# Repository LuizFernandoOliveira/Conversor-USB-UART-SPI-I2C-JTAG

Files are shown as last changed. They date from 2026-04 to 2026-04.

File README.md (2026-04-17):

# Conversor-USB-UART-SPI-I2C-JTAG




## Descrição
Esta PCB trata-se de um poderoso circuito eletrônico que transforma uma única porta USB em múltiplos canais seriais de alta velocidade, ideal para desenvolvedores que precisam de versatilidade em seus projetos.

<p align="center">
  usb2UartSpiI2c
</p>

---

## Descrições técnicas

- Interface USB: Dispositivo USB High-Speed de 480Mbps;
- Possui duas UART (UART0 e UART1), uma SPI, uma I2C, uma JTAG e 8 pinos de GPIOs controlados diretamente pela USB;
- Taxa de Transmissão (Baud Rate): Variável de 1200bps até 6Mbps;
- Alimentação Principal: Requer apenas 3.3V;
- Controle de Fluxo: Suporte completo a Hardware Flow Control (CTS e RTS);
- Buffering (FIFO):
  - RX FIFO: 2048 bytes por UART.
  - TX FIFO: 1024 bytes por UART.
- Configurações UART:
  - Bits de Dados: 8 bits;
  - Paridade: Ímpar, Par e Nenhuma;
  - Bits de Parada: 1 ou 2.

---

## Estrutura do repositório
Os arquivos de hardware foram desenvolvidos utilizando o KiCad 9.0.
- **`.kicad_pcb`**: Layout da placa de circuito impresso (Board).
- **`.kicad_sch`**: Esquemático eletrônico do sistema (Schematic).
- **`.kicad_pro`**: Gerenciador de projeto do KiCad (Project).

---

## Autor
**Dr. Luiz Fernando Pinto de Oliveira**

*Engenheiro Eletrônico especializado em Sistemas Embarcados e Ultra-Low Power.*
- **Website:** [FAPLO](https://faplo.webnode.page/)
- **LinkedIn:** [lfpo](https://www.linkedin.com/in/lfpo/)

---

Shield: [][cc-by-nc-nd]

This work is licensed under a
[Creative Commons Attribution-NonCommercial-NoDerivs 4.0 International License][cc-by-nc-nd].

[][cc-by-nc-nd]

[cc-by-nc-nd]: http://creativecommons.org/licenses/by-nc-nd/4.0/
[cc-by-nc-nd-image]: https://licensebuttons.net/l/by-nc-nd/4.0/88x31.png
[cc-by-nc-nd-shield]: https://img.shields.io/badge/License-CC%20BY--NC--ND%204.0-lightgrey.svg

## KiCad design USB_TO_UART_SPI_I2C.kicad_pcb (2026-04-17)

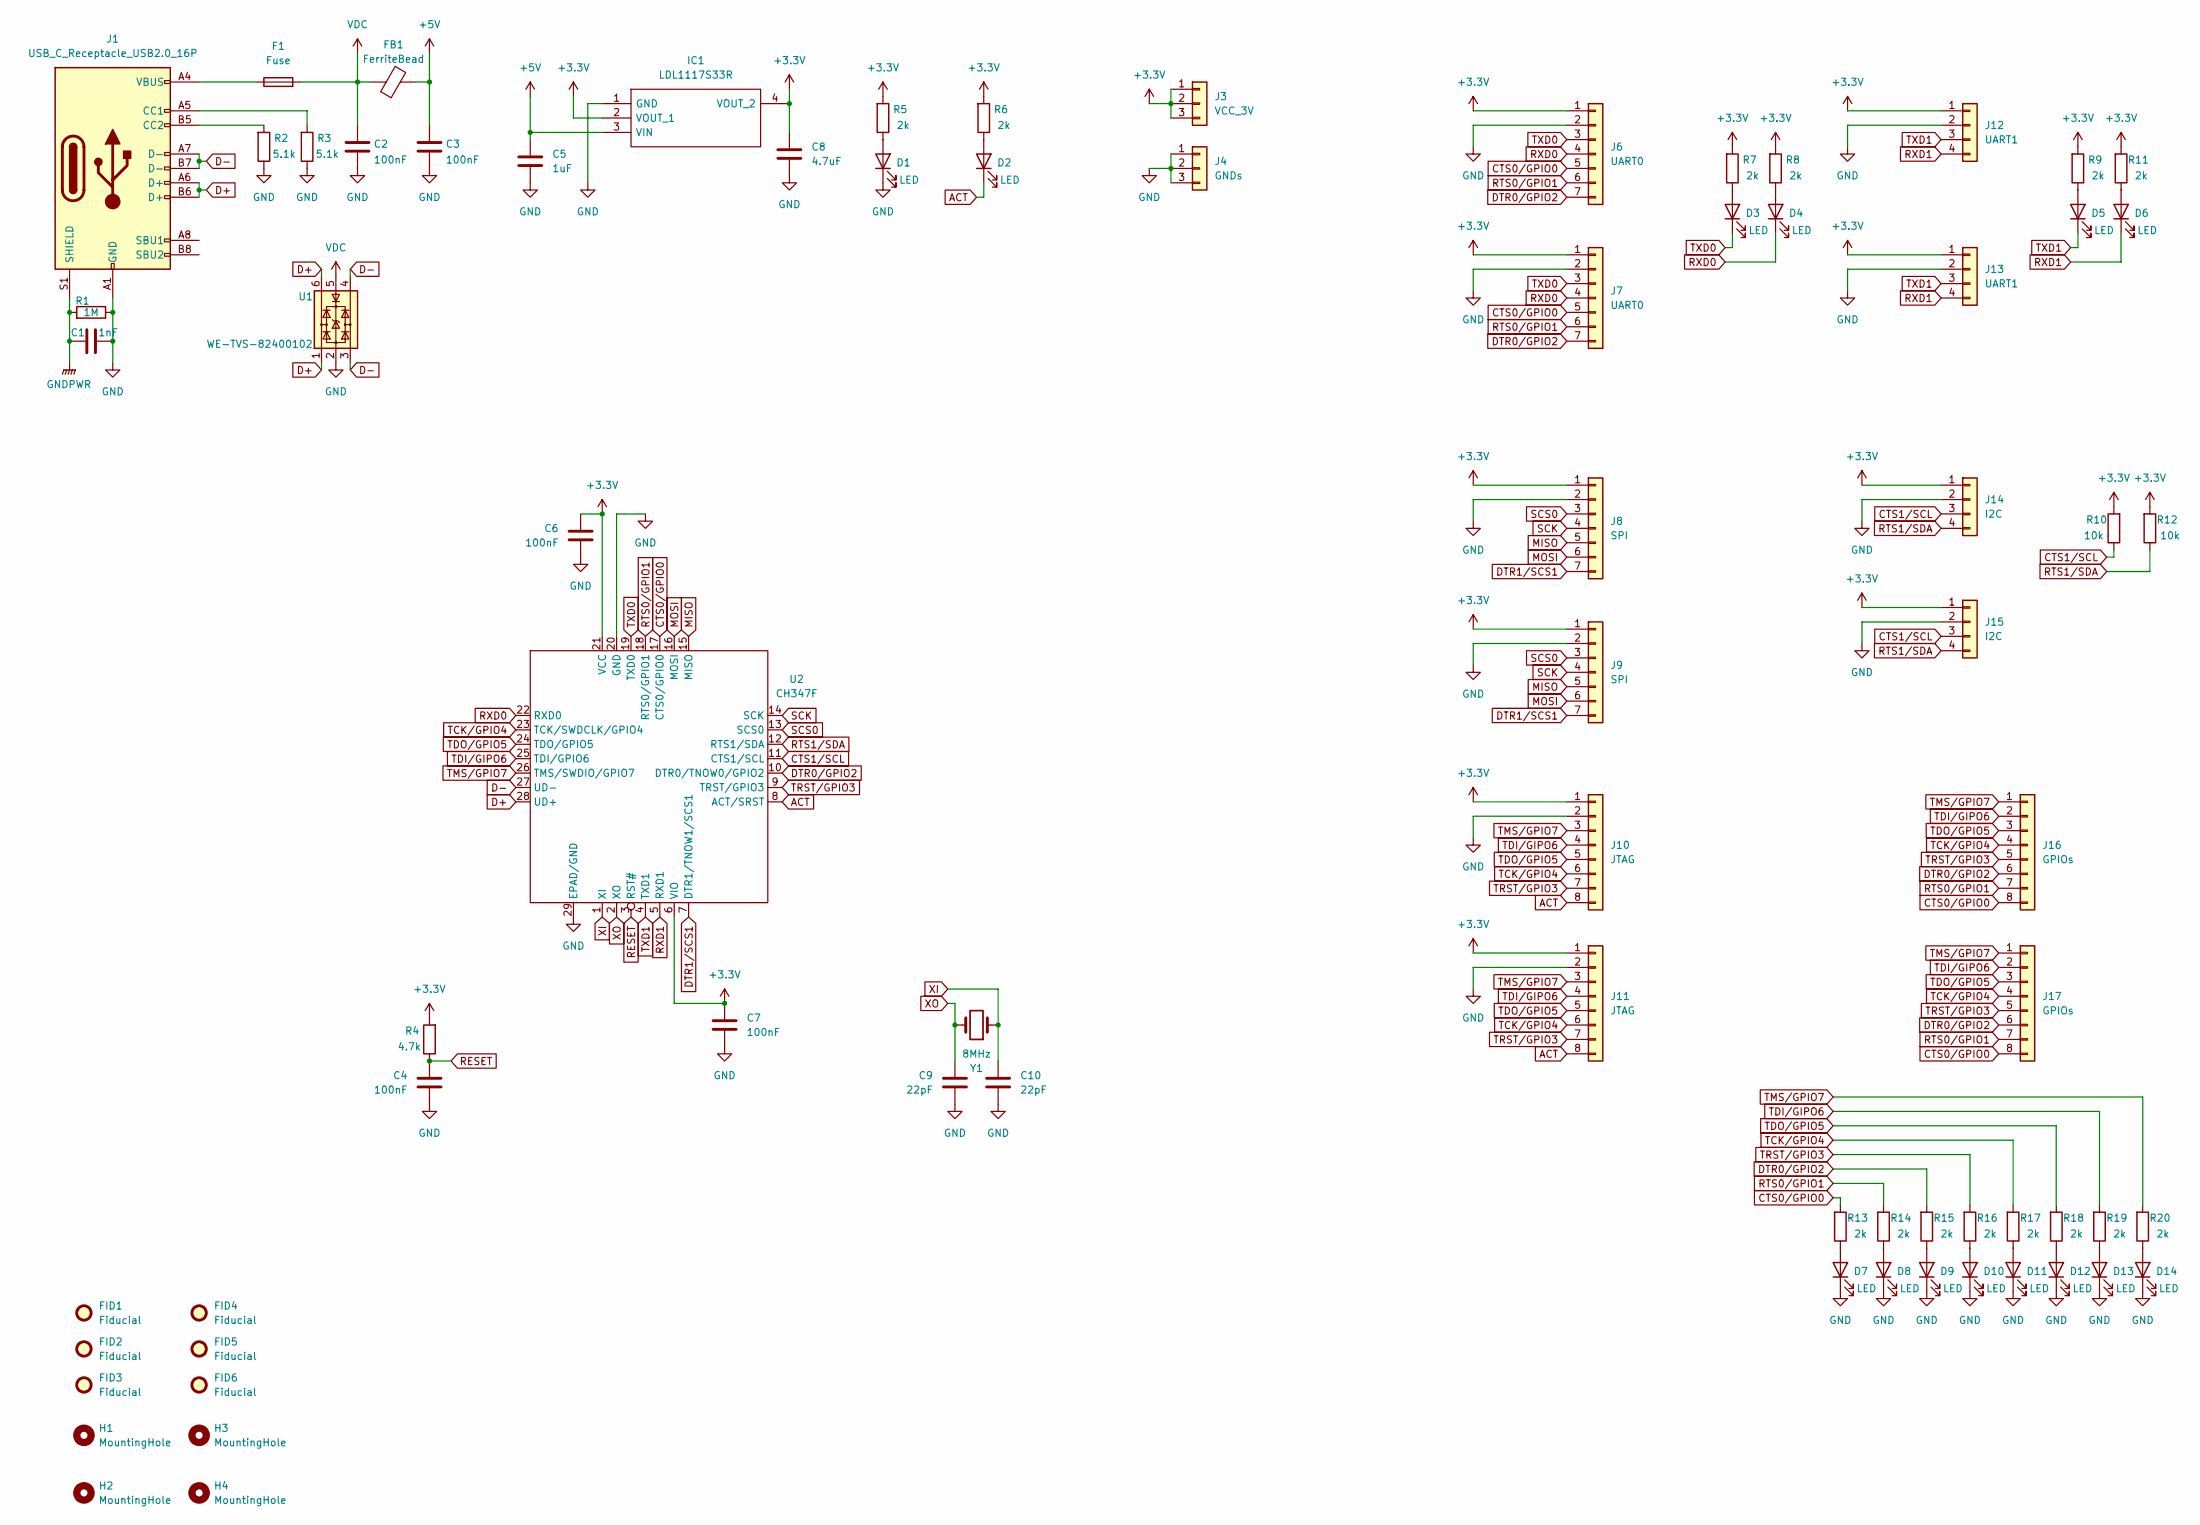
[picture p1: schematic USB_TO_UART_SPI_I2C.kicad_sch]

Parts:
C1: 1nF; C_0805_2012Metric
C2, C3, C4, C6, C7: 100nF; C_0805_2012Metric
C5: 1uF; C_0805_2012Metric
C8: 4.7uF; C_0805_2012Metric
C9, C10: 22pF; C_0805_2012Metric
D1, D2, D3, D4, D5, D6, D7, D8, D9, D10, D11, D12, D13, D14: LED; LED_0805_2012Metric
F1: Fuse; Fuse_0805_2012Metric
FB1: FerriteBead; L_0805_2012Metric
FID1, FID2, FID3, FID4, FID5, FID6: Fiducial; Fiducial_1mm_Mask2mm
H1, H2, H3, H4: MountingHole; MountingHole_3.2mm_M3_DIN965
IC1: LDL1117S33R; SOT230P700X180-4N; Manufacturer_Part_Number LDL1117S33R; Mouser Part Number 511-LDL1117S33R
J1: USB_C_Receptacle_USB2.0_16P; USB_C_Receptacle_HRO_TYPE-C-31-M-12
J3: VCC_3V; PinHeader_1x03_P2.54mm_Vertical
J4: GNDs; PinHeader_1x03_P2.54mm_Vertical
J6: UART0; PinHeader_1x07_P2.54mm_Vertical
J7: UART0; JST_XH_S7B-XH-A_1x07_P2.50mm_Horizontal
J8: SPI; PinHeader_1x07_P2.54mm_Vertical
J9: SPI; JST_XH_S7B-XH-A_1x07_P2.50mm_Horizontal
J10: JTAG; PinHeader_1x08_P2.54mm_Vertical
J11: JTAG; JST_XH_S8B-XH-A-1_1x08_P2.50mm_Horizontal
J12: UART1; PinHeader_1x04_P2.54mm_Vertical
J13: UART1; JST_XH_S4B-XH-A_1x04_P2.50mm_Horizontal
J14: I2C; PinHeader_1x04_P2.54mm_Vertical
J15: I2C; JST_XH_S4B-XH-A_1x04_P2.50mm_Horizontal
J16: GPIOs; PinHeader_1x08_P2.54mm_Vertical
J17: GPIOs; JST_XH_S8B-XH-A-1_1x08_P2.50mm_Horizontal
R1: 1M; R_0805_2012Metric
R2, R3: 5.1k; R_0805_2012Metric
R4: 4.7k; R_0805_2012Metric
R5, R6, R7, R8, R9, R11, R13, R14, R15, R16, R17, R18, R19, R20: 2k; R_0805_2012Metric
R10, R12: 10k; R_0805_2012Metric
U1: WE-TVS-82400102; SOT-23-6
U2: CH347F
Y1: 8MHz; Crystal_SMD_3225-4Pin_3.2x2.5mm

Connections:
+3.3V: C6.1, C7.1, C8.1, IC1.2 (VOUT_1), IC1.4 (VOUT_2), J3.1, J3.2, J3.3, J6.1, J7.1, J8.1, J9.1, J10.1, J11.1, J12.1, J13.1, J14.1, J15.1, R4.2, R5.2, R6.2, R7.2, R8.2, R9.2, R10.2, R11.2, R12.2, U2.6 (VIO), U2.21 (VCC)
+5V: C3.1, C5.1, FB1.2, IC1.3 (VIN)
ACT: D2.1 (K), J10.8, J11.8, U2.8 (ACT/SRST)
CTS0/GPIO0: J6.5, J7.5, J16.8, J17.8, R13.2, U2.17 (CTS0/GPIO0)
CTS1/SCL: J14.3, J15.3, R10.1, U2.11 (CTS1/SCL)
D+: J1.A6 (D+), J1.B6 (D+), U1.1, U1.6, U2.28 (UD+)
D-: J1.A7 (D-), J1.B7 (D-), U1.3, U1.4, U2.27 (UD-)
DTR0/GPIO2: J6.7, J7.7, J16.6, J17.6, R15.2, U2.10 (DTR0/TNOW0/GPIO2)
DTR1/SCS1: J8.7, J9.7, U2.7 (DTR1/TNOW1/SCS1)
GND: C1.2, C2.2, C3.2, C4.2, C5.2, C6.2, C7.2, C8.2, C9.2, C10.2, D1.1 (K), D7.1 (K), D8.1 (K), D9.1 (K), D10.1 (K), D11.1 (K), D12.1 (K), D13.1 (K), D14.1 (K), IC1.1 (GND), J1.A1 (GND), J1.A12 (GND), J1.B1 (GND), J1.B12 (GND), J4.1, J4.2, J4.3, J6.2, J7.2, J8.2, J9.2, J10.2, J11.2, J12.2, J13.2, J14.2, J15.2, R1.1, R2.1, R3.1, U1.2, U2.20 (GND), U2.29 (EPAD/GND)
GNDPWR: C1.1, J1.S1 (SHIELD), R1.2
MISO: J8.5, J9.5, U2.15 (MISO)
MOSI: J8.6, J9.6, U2.16 (MOSI)
unnamed: D1.2 (A), R5.1
unnamed: D2.2 (A), R6.1
unnamed: D3.2 (A), R7.1
unnamed: D4.2 (A), R8.1
unnamed: D5.2 (A), R9.1
unnamed: D6.2 (A), R11.1
unnamed: D7.2 (A), R13.1
unnamed: D8.2 (A), R14.1
unnamed: D9.2 (A), R15.1
unnamed: D10.2 (A), R16.1
unnamed: D11.2 (A), R17.1
unnamed: D12.2 (A), R18.1
unnamed: D13.2 (A), R19.1
unnamed: D14.2 (A), R20.1
unnamed: F1.1, J1.A4 (VBUS), J1.A9 (VBUS), J1.B4 (VBUS), J1.B9 (VBUS)
unnamed: J1.A5 (CC1), R3.2
unnamed: J1.B5 (CC2), R2.2
RESET: C4.1, R4.1, U2.3 (RST#)
RTS0/GPIO1: J6.6, J7.6, J16.7, J17.7, R14.2, U2.18 (RTS0/GPIO1)
RTS1/SDA: J14.4, J15.4, R12.1, U2.12 (RTS1/SDA)
RXD0: D4.1 (K), J6.4, J7.4, U2.22 (RXD0)
RXD1: D6.1 (K), J12.4, J13.4, U2.5 (RXD1)
SCK: J8.4, J9.4, U2.14 (SCK)
SCS0: J8.3, J9.3, U2.13 (SCS0)
TCK/GPIO4: J10.6, J11.6, J16.4, J17.4, R17.2, U2.23 (TCK/SWDCLK/GPIO4)
TDI/GIPO6: J10.4, J11.4, J16.2, J17.2, R19.2, U2.25 (TDI/GPIO6)
TDO/GPIO5: J10.5, J11.5, J16.3, J17.3, R18.2, U2.24 (TDO/GPIO5)
TMS/GPIO7: J10.3, J11.3, J16.1, J17.1, R20.2, U2.26 (TMS/SWDIO/GPIO7)
TRST/GPIO3: J10.7, J11.7, J16.5, J17.5, R16.2, U2.9 (TRST/GPIO3)
TXD0: D3.1 (K), J6.3, J7.3, U2.19 (TXD0)
TXD1: D5.1 (K), J12.3, J13.3, U2.4 (TXD1)
VDC: C2.1, F1.2, FB1.1, U1.5
XI: C10.1, U2.1 (XI), Y1.1
XO: C9.1, U2.2 (XO), Y1.2

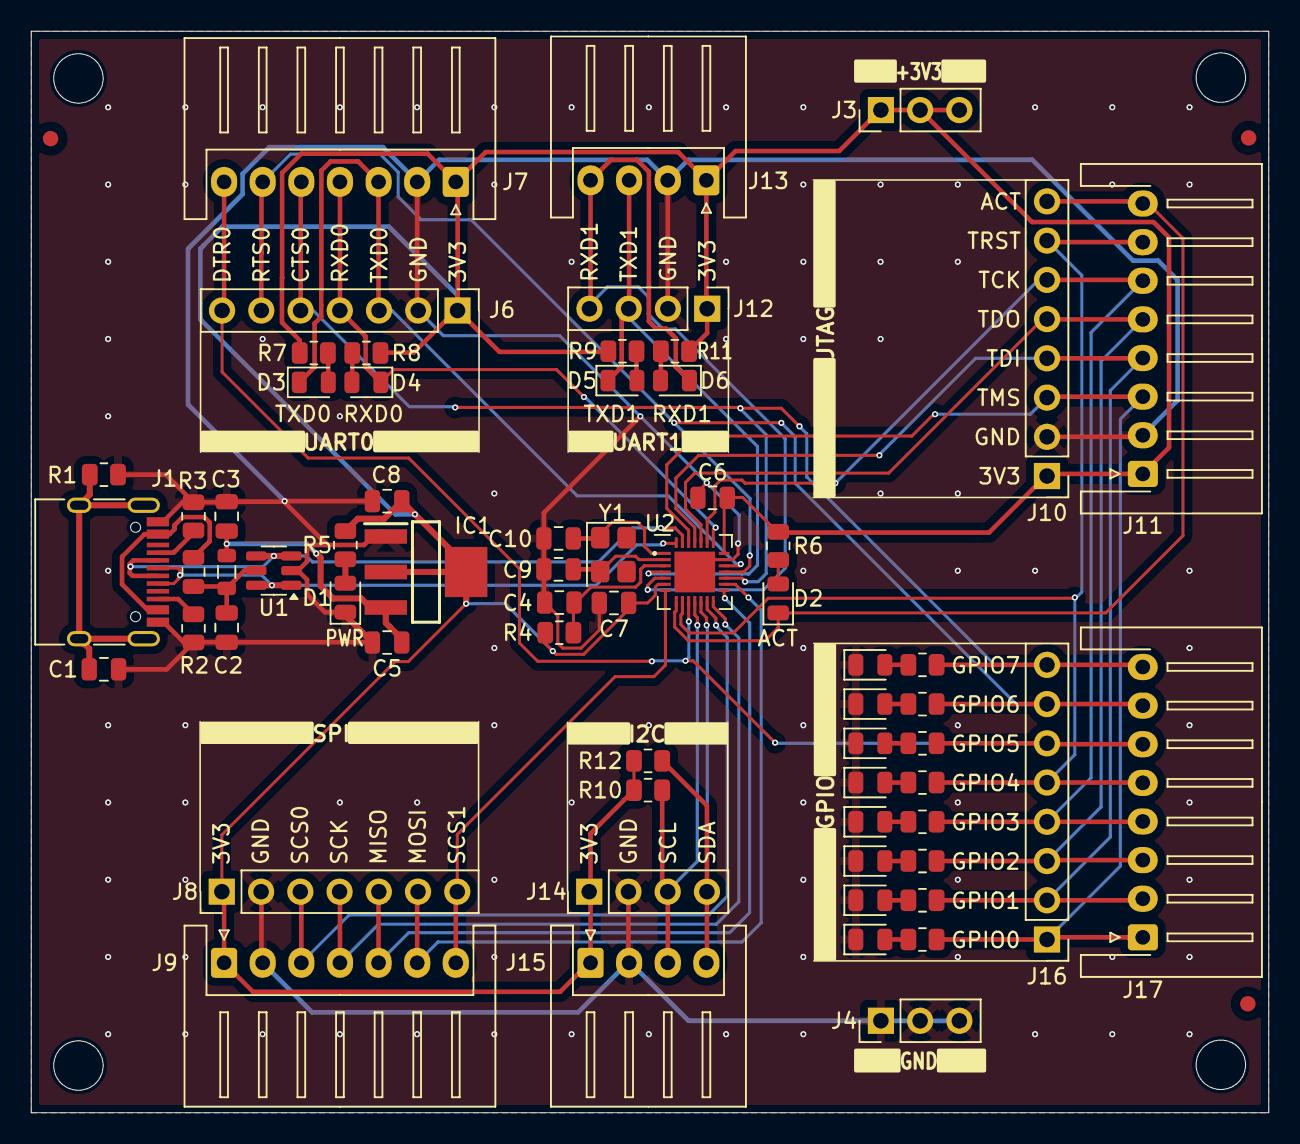
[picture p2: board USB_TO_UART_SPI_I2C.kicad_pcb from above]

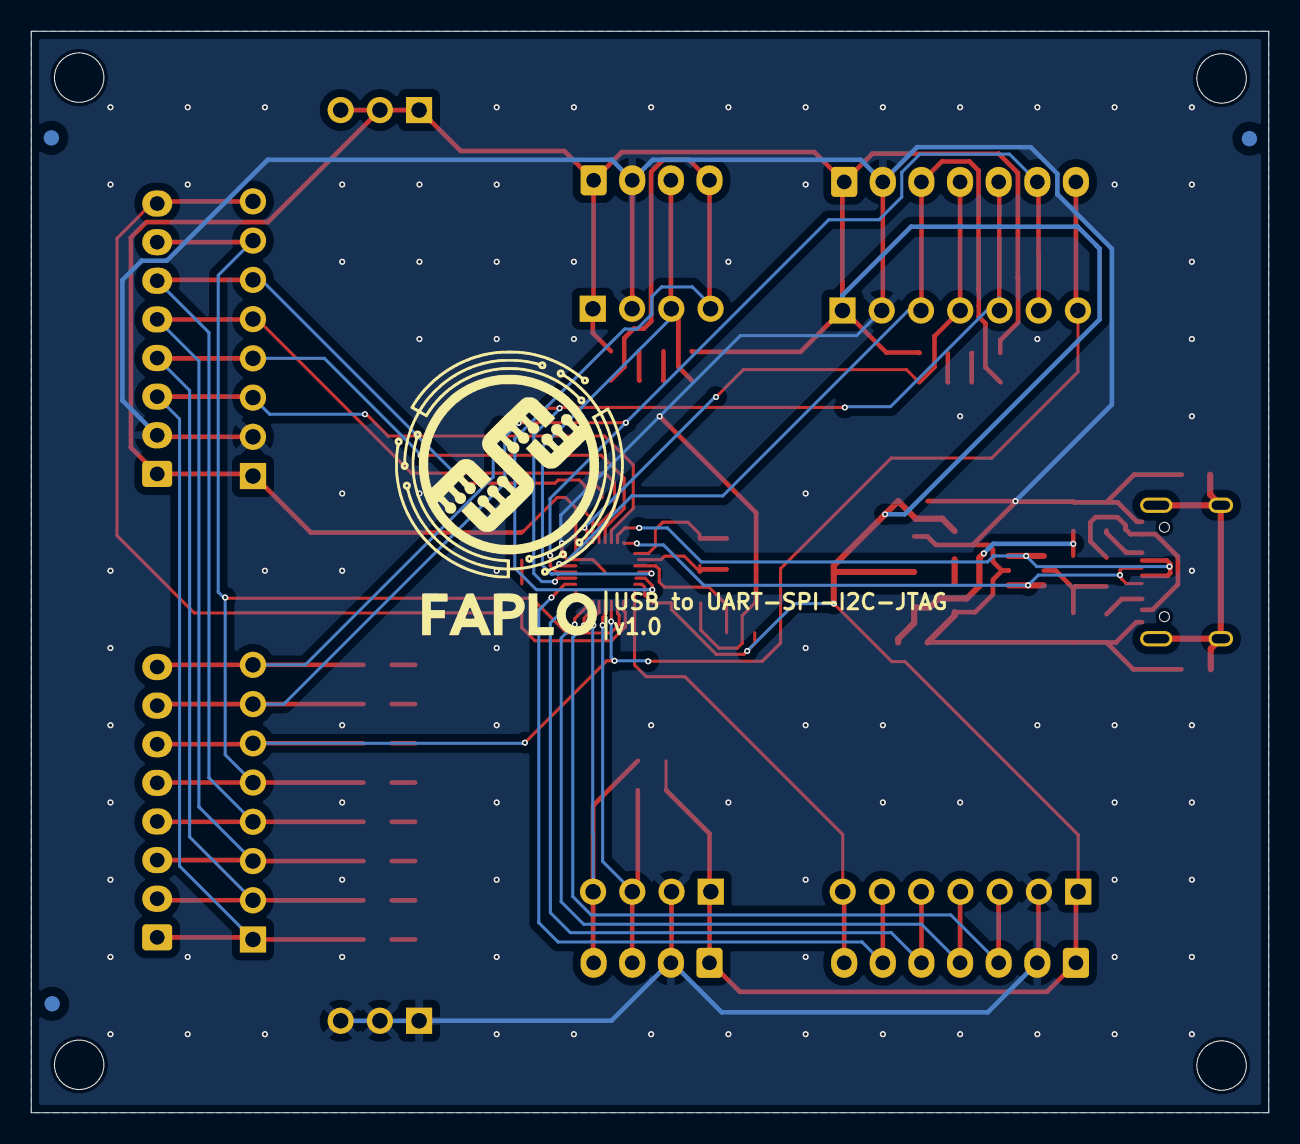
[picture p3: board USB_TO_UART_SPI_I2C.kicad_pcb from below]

Board: 2 copper layers, 80.1 x 70.0 mm, 75 parts (3 on the bottom side), 47 nets.

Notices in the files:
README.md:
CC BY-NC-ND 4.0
